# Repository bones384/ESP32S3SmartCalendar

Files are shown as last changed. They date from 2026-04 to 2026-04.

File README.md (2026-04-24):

# E-Paper Smart Calendar
A low-power smart calendar device that displays upcoming events and weather information on an e-paper screen. Built around the ESP32-S3, the system is designed for long battery life, minimal power consumption, and reliable offline persistence.
Built around the ESP32-S3, the system is designed for long battery life, minimal power consumption, and reliable offline persistence.

## Features
- Google Calendar & weather integration: Fetches event data from the user's Google Calendar and weather forecast information from open-meteo.
  - Synced data is cached and saved to FRAM, avoiding the need to resync on every reboot, saving power.
- Ultra-low power system with aggressive power gating: The entire system is power gated using a P-MOSFET and a TPL5110, waking periodically to update the display.
  - Network sync is expensive in terms of power, and as such only happens every few automatic wakes.
  - WiFi remains disabled outside of sync cycles.
  - E-paper display retains the image without power
  - Powered by 4xAA batteries (designed for NiMH),
  - Will display warning and reduce power usage to minimum if voltage goes under a safe threshold.
> [!NOTE]
> These power saving techniques reduce the idle power usage to under a microampere, with short bursts of power consumption during a wake cycle.
> This increases battery life significantly.
- Interactive mode: The user can wake the device and browse events/forecasts for upcoming days.
- ESP SoftAP WiFi Provisioning: Network credentials can be configured from a mobile device using Espressif’s provisioning tools.
- Google API tokens are provisioned via serial connection and automatically refreshed when expired.
- Displays indoor temperature and humidity using onboard sensors.

## Key Components

* ESP32-S3 DevkitC-1
* Adafruit SHT40 breakout board (ADAFRUIT4885)
* 4MBit FRAM IC: MB85RS4MTPF-G-BCERE1, with a matching DIP adapter
* Pololu 3.3V step-down voltage regulator module DT24V10F3
* Waveshare 13353 4.2 inch E-Paper module
* TPL5110 Low Power Timer (with matching DIP adapter)
  
A full BOM can be found in the project report in the docs directory.

## Media

High-level system diagram:
system-diagram
Software flow diagram:
flowidag

## Notes
Includes full schematic (.sch) and PCB layout (.brd) files.
Designed as a custom PCB and manufactured via JLCPCB.
All components were hand-soldered and the device was fully assembled and tested.
The /docs directory contains a detailed report with the BOM, assembly guide, and operating instructions.

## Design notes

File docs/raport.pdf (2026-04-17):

| Katedra Grafiki Wizji Komputerowej i Systemów Cyfrowych Raport z projektu SMiW

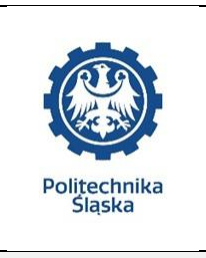
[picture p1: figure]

Rok akademicki | Rodzaj studiów*: SSI Glw/SSI Ktw/NSI Glw | Dizeń tygodnia i godzina zajęć: | Numer sekcji:
2025/2026 | SSI Glw | Środa 11:30 | 7
Imię: Nazwisko: | Mateusz | Prowadzący (inicjały): OA/JP/GB/KP | JP

## Kowalec

## Temat projektu

# Smart Calendar

Opis głównych założeń projektu:

- Wyświetlacz e-papier
- Pobiera dane o prognozie pogody oraz wydarzenia z kalendarza użytkownika z Internetu
- Wyświetla aktualną godzinę oraz zmierzoną temperaturę i wilgotność otoczenia
- Konfiguracja ustawień sieci przez BT

Rodzaj zasilania:

- Zasilanie bateryjne (AA NiMH)

Mateusz Kowalec INF-4 | Raport projektu SMIW | Bytom, 12 Luty 2026

## Szczegółowy opis funkcjonalności projektu:

Celem projektu jest stworzenie „mądrego” kalendarza. Podobnie do wersji papierowej, będzie można zaobserwować na nim aktualną datę, dowiedzieć się, czy danego dnia nie wypada święto, czyje są imieniny itd. Jedną z przewag takiego urządzenia nad tradycyjnym jest to, że po zamontowaniu w miejscu docelowym wymaga jedynie okazjonalnej wymiany baterii, a nie corocznej zmiany.

Jako urządzenie „mądre” będzie pokazywać prognozę pogody na najbliższe parę tygodni, pobraną z ogólnodostępnego API, Open-Meteo, oraz wydarzeń z kalendarza użytkownika w Google Calendar. Możliwe jest „przybliżenie” konkretnego dnia, co pozwoli wyświetlić dokładniejszą prognozę pogody (godzinową) oraz wydarzenia występujące w danym dniu. Dla dodatkowej wygody kalendarz będzie również wyświetlać aktualną godzinę, temperaturę, oraz wilgotność – jednocześnie zastępuje więc kalendarz, planer, zegar, pogodynkę, termometr oraz higrometr.

By zwiększyć komfort użycia (i zmniejszyć zużycie baterii) wykorzystany został wyświetlacz epapier. Celem wydłużenia żywotności baterii, urządzenie będzie spędzać większość czasu w stanie spoczynku, wybudzając się jedynie co minutę w celu aktualizacji czasu na wyświetlaczu. Natomiast raz na konfigurowalny okres czasu urządzenie będzie wybudzać się celem połączenia z internetem, pobraniem nowych danych pogodowych oraz kalendarzowych, zsynchronizowanie czasu, wyłączenia radia, zaktualizowania wyświetlacza oraz jak najszybszego odcięcia sobie zasilania.

Interakcja użytkownika, rozpoczynana przyciskiem włączenia na płytce, wykonywana przełącznikiem nawigacyjnym podobnym w obsłudze do selektora na pilocie do telewizora, wybudza urządzenie z uśpienia, do którego powróci po dłuższym czasie bezczynności.

By nie musieć przeprogramowywać urządzenia w przypadku zmian ustawień sieciowych lub zmiany lokalizacji, dane o WiFi będą aktualizowane za pomocą aplikacji na telefonie (ESP WiFi provisioning, oryginalnie miało być to BLE, ostatecznie jest SoftAP, więcej we wnioskach).

Udzielanie dostępu do usług Google użytkownika jest wykonywane za pomocą przesłania kodu dostepu Google API przy pierwszym uruchomieniu urządzenia przez kabel USB podpięty do komputera. Urządzenie będzie zasilane bateriami AA NiMH. Bateriami, bo domyślnie ma zostać zamontowane na ścianie lub przypięte do tablicy korkowej, gdzie będzie wisieć nieściągane przez cały swój okres używania, a akumulatorki NiMH – bo takie wraz z ładowarką mam pod ręką.

## Wybory najważniejszych części:

Czujnik wilgoci/temperatury:
| HDC3020 | HDC1000YPAR | Sensirion SHTC3 | Sensiron SHT40
Dokładność pomiarów | +/- 0,1C, +-0,5% | +/- 0,2C, +-3% | +-0,2C, +-2% | +-0,1C +-1.0%
Zakres temperatur | -40 do 125C | -40C do 125C | -40C do 125C | -40 do 125C
Interfejs | I2C | I2C | I2C | I2C
Napięcie zasilania | 1.6V-5.5V | 3V - 5V | 1,62V-3,6V | 1,08V-3,6V
Czas reakcji pomiaru RH | 4s | 15s | 8s | 6s
Sprawiłby się tu dowolny czujnik o dokładności temperatury ok. +/- 0.1C i wilgotności +/- 1%. Oryginalnie planowałem zamówić sam czujnik HDC3020, natomiast okazał się on zbyt mały by ręcznie go lutować (szczególnie, że nie mam płyty grzewczej). Zamówiłem więc breakout board SHT40 Adafruita, bo również spełnia moje wymagania, był w momencie zamawiania części dostępny w polskich magazynach i jest w akceptowalnej dla mnie cenie.

Przełącznik 5-kierunkowy:
Oryginalnie planowałem wybrać Adafruit SKQUCAA010, natomiast w celu zmniejszenia kosztów dostawy zamówiłem od innego dostawcy prawie identyczny przełącznik E-Switch JS5208. Projekt działałby praktycznie identycznie gdyby zamiast tego przełącznika dać np. 5 tact switchy, natomiast pojedyńczy przełącznik wygodniej się obsługuje.

Przetwornica:
| Pololu D24V10F3 | TI TPS62840 | Analog Devices ADP2370
Maks. prąd wyj. | 1A | 750mA | 3A
Min. napięcie wej. | 3,5V | 1,8V | 3,2V
IQ | 1-4mA | 60nA | 34uA
Sprawdziłby się tu dowolny moduł przetwornicy Buck 3.3V, umożliwiający pobór przynajmniej 1A przy VIn=4V (Dropout voltage @1A = 0.7V lub mniej).
Wybrałem Pololu D24V10F3, bo to gotowy i prosty w zastosowaniu moduł z induktorem na płytce, który na pewno przyda mi się do przyszłych projektów. Prąd spoczynkowy okazał się nie mieć tutaj znaczenia - w stanie czuwania układu wejście zasilania przetwornicy jest kompletnie odcięte.

Mikrokontroler:
| ESP32-S3-DEVKIT-C1 | ESP32-C6-DevkitM-1 | ESP32-C3-DevKitM-1
Procesor | ESP32-S3-WROOM-1 | ESP32-C3-MINI-1 | ESP32-C6-MINI-1
Rdzenie | 2 | 1 | 1
Pobór prądu w stanie uśpienia | Kilka uA
GPIO | 45 | 22 | 13
WiFi, BT | Tak | Tak | Tak
Wybrana została płytka rozwojowa ESP32-S3-DevKitC-1. Dużymi atutami tych mikrokontrolerów jest własna aplikacja do WiFi provisioning Espressif’a (ESP BLE/SoftAP Provisioning) + odpowiednia biblioteka, wbudowane wsparcie BT/WiFi + antena, niski pobór prądu (szczególnie w stanach uśpienia, choć końcowo nie miało to znaczenia), pełna kompatybilność z bibliotekami Arduino (pod warunkiem odpowiedniego skonfigurowania środowiska esp-idf) oraz niska cena. W ramach projektu z semestru letniego miałem już okazję zaznajomić się z procesorami z tej rodziny, a ten konkretny devkit już posiadam (nawet w dwóch egzemplarzach).

Projekt został zrealizowany w Autodesk EAGLE / ESP-IDF(Wersja linuksowa) + CLion + Arduino (IDF Component) .

## Schemat blokowy urządzenia:

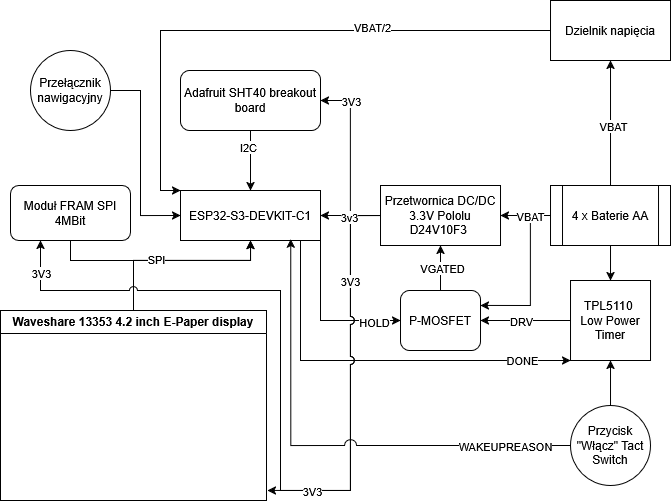
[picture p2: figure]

## Schemat ideowy:

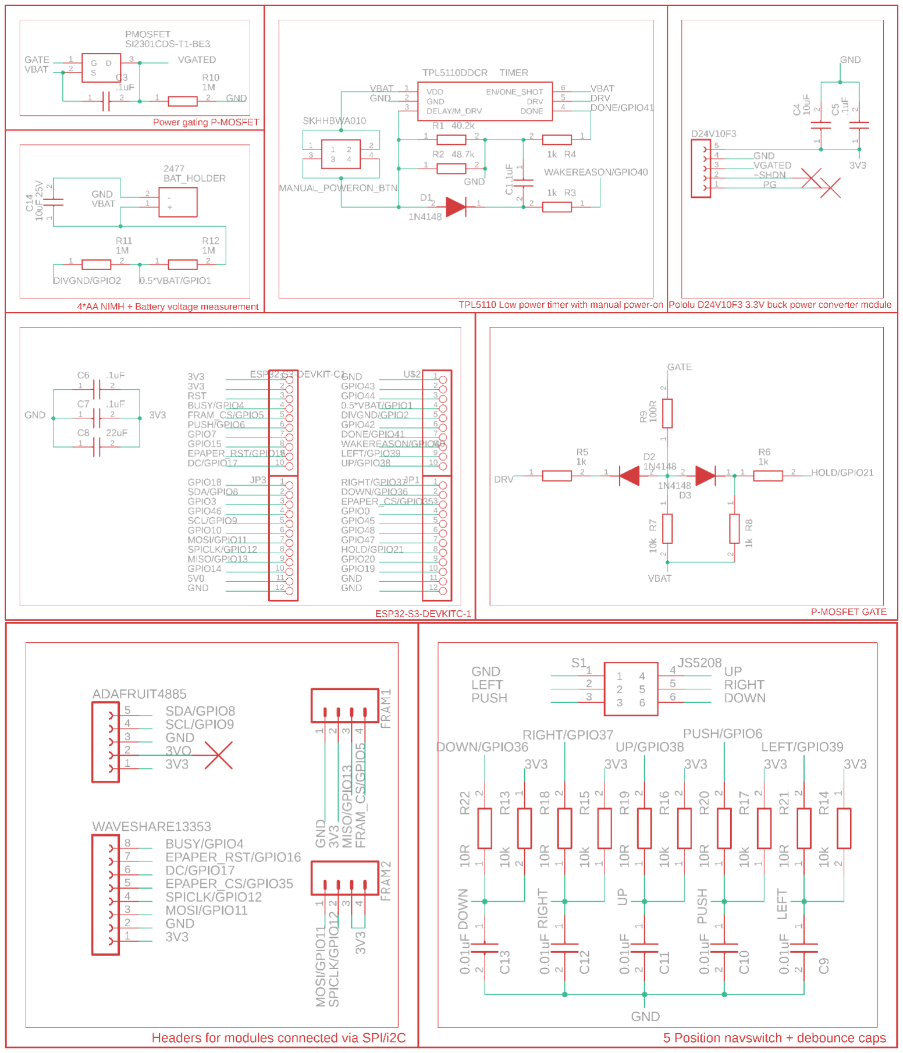
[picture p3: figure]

## Opis funkcji bloków/elementów

Blok przetwornica – mikrokontroler – wyświetlacz + czujniki + przełącznik nawigacyjny raczej nie potrzebuje wytłumaczenia. O wiele ciekawszy natomiast jest blok bramkowania zasilania, składający się z TPL5110 Low Power Timer, tranzystora MOSFET z kanałem typu P oraz tact switcha.

Potrzebujemy wybudzać mikrokontroler tylko raz na minutę (celem aktualizacji informacji na wyświetlaczu: zegara oraz informacji z czujników – taki układ pozwala uzyskać prawie zerowy prąd spoczynkowy, wtedy kiedy tylko TPL5110 pobiera prąd max 50nA. Same działanie bloku jest proste: Tranzystor kontroluje przepływ prądu pomiędzy VBAT a VIN przetwornicy, odcinając przetwornice oraz całą resztę układu do niej podłączonego od zasilania.

TPL5110 co konfigurowalną (poprzez opór na wejściu DELAY/M_DRV) długość czasu, nazwijmy ją t, generuje stan niski na wyjściu DRV, podłączonym do bramki tranzystora. Bez żadnej interakcji ze strony mikrokontrolera układ utrzymywałby stan niski na DRV przez t − 50ms, po czym na ostatnie 50ms cyklu ustawiłby tam stan wysoki, odcinając na chwilę zasilanie i restartując układ. Mikrokontroler może przekazać timerowi informację o zakończeniu pracy, wysyłając odpowiedni impuls na wejście DONE, co skutkuje natychmiastowym odcięciem zasilania. Co ważne, timer generuje impulsy na DRV dokładnie co t, niezależnie od wysłania sygnału DONE.

Timer ma również funkcję ręcznego włączenia, realizowaną poprzez osobny tact switch przy układzie zasilającym, podpięty do jego wejścia DELAY/M_DRV. Naciśnięcie przycisku skutkuje nadaniem napięcia VDD na to wejście, co powoduje ustawienie linii DRV na stan niski (nie wpływając na odliczanie czasu przez timer!). Przycisk jest również podłączony do procesora, wraz z
kondensatorem "przetrzymującym" informację o naciśnięciu przycisku (timer reaguje na ręczne włączenie z lekkim opóźnieniem), co pozwala po włączeniu mikrokontrolera sprawdzić czy wybudzenie było automatyczne, czy ręczne, i odpowiednio dopasować tok programu. Oprócz timera, do bramki tranzystora podłączone jest również wyjście procesora, nazwane przeze mnie "HOLD", które procesor zaraz po wybudzeniu zwiera do masy. Dopuki HOLD = GND, procesor nie utraci zasilania, nawet jeśli timer odliczy minutę od ostatniego autmatycznego impulsu (DRV i HOLD przechodzą przez diody sygnałowe, mogą więc jedynie wpłynąć na bramkę ustawiając stan niski lub GND, co skutkuje włączeniem zasilania, natomiast żadne ze źródeł nie może wywołać tam stanu wysokiego, który jest domyślnie osiągany poprzez rezystor podciągający.

Cykl działania bloku wygląda więc następująco:
1. TPL5110 albo w skutek upłynięcia czasu t lub naciśnięcia przycisku ustawia DRV na stan niski
2. Mosfet przewodzi: Przetwornica zasila procesor
3. Procesor po włączeniu podtrzymuje zasilanie ustawiając hold na gnd
4. Procesor odczytuje informację o powodzie wybudzenia z linii WAKEREASON
5. Procesor wykonuje swoje zadania
6. Po zakończeniu działania, procesor najpierw wysyła impuls na linię DONE, by zasygnalizować TPL5110 by tamten przestał podtrzymywać zasilanie jeśli aktualnie to robi. Teraz DRV jest w stanie wysokim, i nie wpływa na bramkę tranzystora. Tylko HOLD utrzymuje teraz zasilanie.
7. Procesor ustawia HOLD na stan wysokiej impedancji, odcinając zasilanie do przetwornicy i co za tym idzie do reszty układu. Układ zużywa teraz znikomy prąd w oczekiwaniu na kolejne wydarzenie, które skutkowałoby wybudzeniem.

By jeszcze bardziej skapitalizować na bramkowaniu zasilania, do układu dodano moduł F-RAM 4Mbit RAMXEED (MB85RS4MTPF-G-BCERE1), co umożliwia cachowanie danych pobranych z internetu pomiędzy uruchomieniami. Pozwala to przez większość tych uruchomień nie włączać radia, a jedynie pobierać zcachowane dane z modułu. W NVS procesora przechowywany jest ostatni zsynchronizowany timestamp, oraz liczba wybudzeń do pełnej synchronizacji. Aktualny czas jest wyliczany ufając częstotliwości automatycznych wybudzeń jako czas ostatniej syncℎronizacji +
liczba wybudzeń od ostatniej syncℎronizacji ∗ 60s. Procesor tylko co parę automatycznych uruchomień / przy ręcznym pobiera świeże dane z internetu.

## Projekt płytki/schemat montażowy

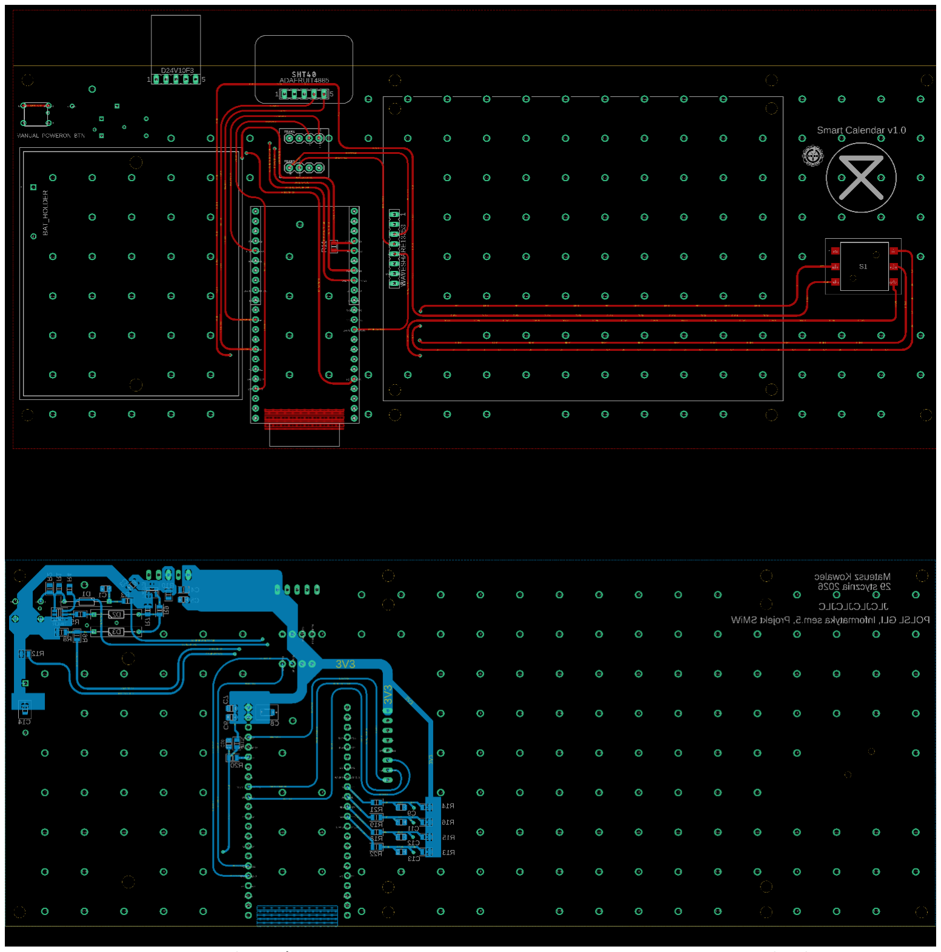
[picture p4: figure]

Zdjęcia warstwy górnej/dolnej płytki pcb. Pola masy, dla lepszej widoczności ścieżek i komponentów, zostały ukryte – w rzeczywistości wypełniają całe pozostałe wolne miejsce na płytce.

## Lista elementów (BoM, export z EAGLE):

Part | Value | Device | Package | Description
Adafruit SHT40 | | ADAFRUIT4885 | | Temperature & Humidity Sensor
BAT_HOLDER | 2477 | 2477 | 2477 | Cylindrical Battery Contacts, Clips, Holders & Springs 4AA PLASTIC HOLDER
C1 | .1uF | 0805ZC104JAZ2A | CAPC2012X94N | Multilayer Ceramic Capacitors MLCC -SMD/SMT 10V .1uF X7R 0805 5% Tol FLEX
C3 | .1uF | 0805ZC104JAZ2A | CAPC2012X94N | Multilayer Ceramic Capacitors MLCC -SMD/SMT 10V .1uF X7R 0805 5% Tol FLEX
C4 | 10uF | GCM21BR71A106K E22L | CAPC2012X140N | Murata GCM21BR71A106KE2 2L 10uF Multilayer Ceramic Capacitor MLCC 10V dc +/-10% Tolerance SMD
C5 | .1uF | 0805ZC104JAZ2A | CAPC2012X94N | Multilayer Ceramic Capacitors MLCC -SMD/SMT 10V .1uF X7R 0805 5% Tol FLEX
C6 | .1uF | 0805ZC104JAZ2A | CAPC2012X94N | Multilayer Ceramic Capacitors MLCC -SMD/SMT 10V .1uF X7R 0805 5% Tol FLEX
C7 | .1uF | 0805ZC104JAZ2A | CAPC2012X94N | Multilayer Ceramic Capacitors MLCC -SMD/SMT 10V .1uF X7R 0805 5% Tol FLEX
C8 | 22uF | GRM31CR71A226K E15L | GRM31X | MLCC, 1206
C9 | 0.01u F | 0805ZC103KAT2A | CAPC2012X94N | Capacitor 0805 10000PF +/-10% 10V
C10 | 0.01u F | 0805ZC103KAT2A | CAPC2012X94N | Capacitor 0805 10000PF +/-10% 10V
C11 | 0.01u F | 0805ZC103KAT2A | CAPC2012X94N | Capacitor 0805 10000PF +/-10% 10V
C12 | 0.01u F | 0805ZC103KAT2A | CAPC2012X94N | Capacitor 0805 10000PF +/-10% 10V
C13 | 0.01u F | 0805ZC103KAT2A | CAPC2012X94N | Capacitor 0805 10000PF +/-10% 10V
C14 | 10uF 25V | GCM21BC71E106K E36K | GCM21 | Chip Multilayer Ceramic Capacitors for Automotive

| | | | (Powertrain/Safety), 1.6 x 0.8 (0603)
D1 | 1N41 48 | 1N4148 | DIOAD1150W50L390 D190 | Diodes - General Purpose, Power, Switching Small Signal Diode, DO-35, 100V, 0.2A, 175C
D2 | 1N41 48 | 1N4148 | DIOAD1150W50L390 D190 | Diodes - General Purpose, Power, Switching Small Signal Diode, DO-35, 100V, 0.2A, 175C
D3 | 1N41 48 | 1N4148 | DIOAD1150W50L390 D190 | Diodes - General Purpose, Power, Switching Small Signal Diode, DO-35, 100V, 0.2A, 175C
D24V10F3 | | Pololu D24V10F3 | | Pololu 3.3V, 1A Step-Down Voltage Regulator D24V10F3
ESP32-S3-DEVKIT-C1 | | | ESP32-S3-DEVKIT-C1 | WiFi Development Tools - 802.11 WiFi Development Tools -802.11 ESP32-S3 general-purpose development board, embeds ESP32-S3-WROOM-1, 8 MB Quad flash and 8MB Octal PSRAM, with pin header
FRAM1 | | CONN_04PTH | 1X04 | Multi connection point. Often used as Generic Header-pin footprint for 0.1 inch spaced/style header connections
FRAM2 | | CONN_04PTH | 1X04 | Multi connection point. Often used as Generic Header-pin footprint for 0.1 inch spaced/style header connections
FRAM | | MB85RS4MTPF-G-BCERE1 | | F-RAM F-RAM 4Mbit FeRAM with SPI interface - SOP8 (208mil) T&R
JP1 | | PINHD-1X12-CB | 1X12-CB | PIN HEADER
JP3 | | PINHD-1X12-CB | 1X12-CB | PIN HEADER
MANUAL_POWERON _BTN | | SKHHBWA010 | SKHHALA010 | Tact switch,PCB,SPST,grey, 1.57N op/force Grey Stem Tactile Switch, SPST-NO 50 mA 7mm
PMOSFET | | SI2301CDS-T1-BE3 | SOT95P237X112-3N | MOSFET P-CHANNEL 20-V (D-S)
R1 | 40.2k | CR0805-FX-4022ELF | RESC2012X60N | Thick Film Resistors -SMD 40.2K 1%
R2 | 48.7k | CR0805-FX-4872ELF | RESC2012X60N | Thick Film Resistors -SMD 48.7K 1%
R3 | 1k | CRCW08051K00FK TC | RESC2012X50N | VISHAY -CRCW08051K00FKTC

| | | | - RES, THICK FILM, 1K, 1%, 0.125W, 0805
R4 | 1k | CRCW08051K00FK TC | RESC2012X50N | VISHAY -CRCW08051K00FKTC - RES, THICK FILM, 1K, 1%, 0.125W, 0805
R5 | 1k | CRCW08051K00FK TC | RESC2012X50N | VISHAY -CRCW08051K00FKTC - RES, THICK FILM, 1K, 1%, 0.125W, 0805
R6 | 1k | CRCW08051K00FK TC | RESC2012X50N | VISHAY -CRCW08051K00FKTC - RES, THICK FILM, 1K, 1%, 0.125W, 0805
R7 | 10k | RK73H2ATTE1002F | RESC2012X60N | Thick Film Resistors SMD1/4watts10Kohms 1%
R8 | 1k | CRCW08051K00FK TC | RESC2012X50N | VISHAY -CRCW08051K00FKTC - RES, THICK FILM, 1K, 1%, 0.125W, 0805
R9 | 100R | CRCW0805100RFK EA | RESC2012X50N | Vishay CRCW Series Thick Film Surface Mount Resistor 0805 Case 100?? ??1% 0.125W ??100ppm/??C
R10 | 1M | MCU08050C1004FP 500 | RESC2012X62N | 1 MOhms +/-1% 0.2W, 1/5W Chip Resistor 0805 (2012 Metric) Anti-Sulfur Thin Film
R11 | 1M | MCU08050C1004FP 500 | RESC2012X62N | 1 MOhms +/-1% 0.2W, 1/5W Chip Resistor 0805 (2012 Metric) Anti-Sulfur Thin Film
R12 | 1M | MCU08050C1004FP 500 | RESC2012X62N | 1 MOhms +/-1% 0.2W, 1/5W Chip Resistor 0805 (2012 Metric) Anti-Sulfur Thin Film
R13 | 10k | RK73H2ATTE1002F | RESC2012X60N | Thick Film Resistors SMD1/4watts10Kohms 1%
R14 | 10k | RK73H2ATTE1002F | RESC2012X60N | Thick Film Resistors SMD1/4watts10Kohms 1%
R15 | 10k | RK73H2ATTE1002F | RESC2012X60N | Thick Film Resistors SMD1/4watts10Kohms 1%
R16 | 10k | RK73H2ATTE1002F | RESC2012X60N | Thick Film Resistors SMD1/4watts10Kohms 1%
R17 | 10k | RK73H2ATTE1002F | RESC2012X60N | Thick Film Resistors SMD1/4watts10Kohms 1%
R18 | 10R | CRCW0805100RFK EA | RESC2012X50N | Vishay CRCW Series Thick Film Surface Mount Resistor 0805 Case 100?? ??1% 0.125W ??100ppm/??C
R19 | 10R | CRCW0805100RFK EA | RESC2012X50N | Vishay CRCW Series Thick Film Surface

| | | | Mount Resistor 0805 Case 100?? ??1% 0.125W ??100ppm/??C
R20 | 10R | CRCW0805100RFK EA | RESC2012X50N | Vishay CRCW Series Thick Film Surface Mount Resistor 0805 Case 100?? ??1% 0.125W ??100ppm/??C
R21 | 10R | CRCW0805100RFK EA | RESC2012X50N | Vishay CRCW Series Thick Film Surface Mount Resistor 0805 Case 100?? ??1% 0.125W ??100ppm/??C
R22 | 10R | CRCW0805100RFK EA | RESC2012X50N | Vishay CRCW Series Thick Film Surface Mount Resistor 0805 Case 100?? ??1% 0.125W ??100ppm/??C
S1 | | JS5208 | | JS5208 NAVIGATION, Surface Mount
TIMER | | TPL5110DDCR | SOT95P280X110-6N | Timers & Support Products Ultr LowPowrTimerMOS drivr MOSFET Powr
U$2 | | PINHD-1X10 | 1X10-BIG | Pin header 1x10 0.1" spacing
WAVESHARE13353 | | WAVESHARE13353 | | 4.2inch e-Paper Module

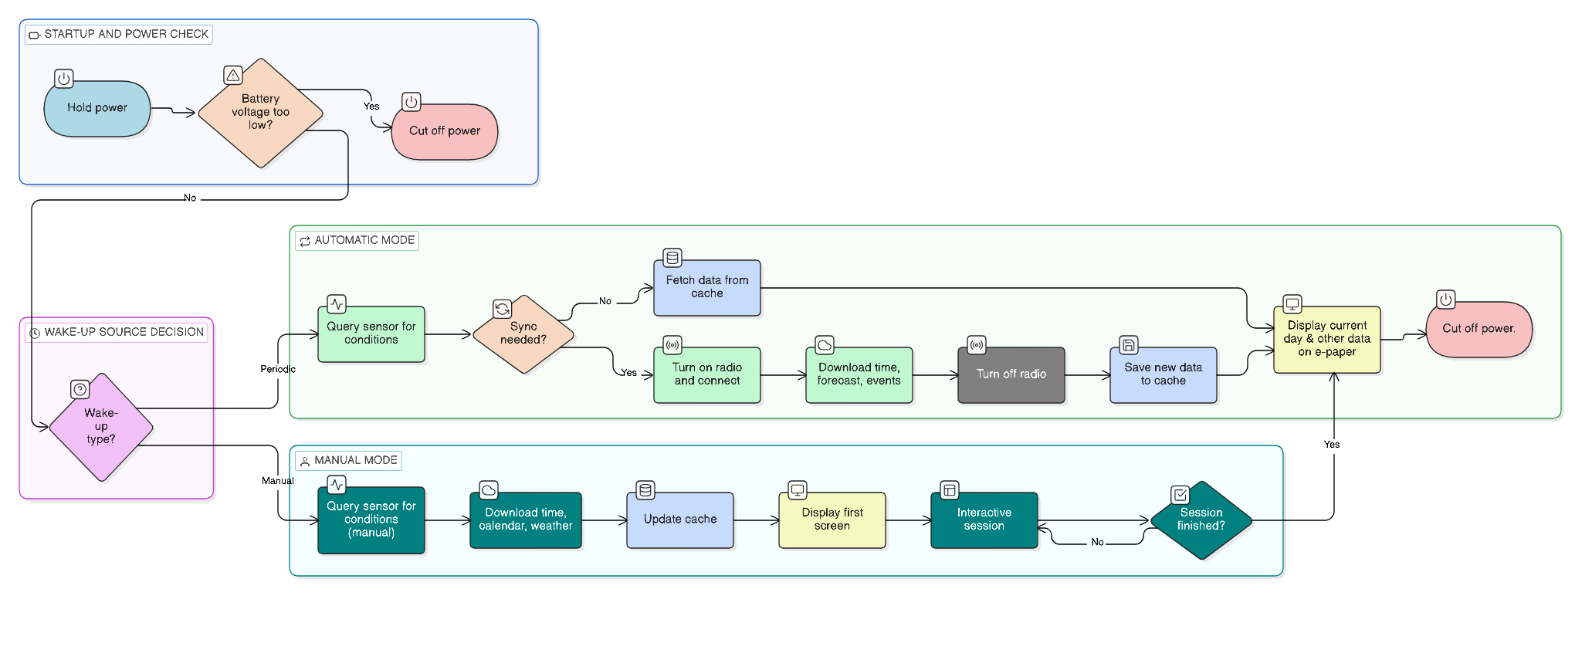
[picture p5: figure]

## Algorytm oprogramowania

- Tok programu:
- Podtrzymanie zasilania (HOLD = GND)
- Sprawdzenie czy napięcie na baterii nie jest zbyt niskie (jeśli tak – od razu odcinamy zasilanie DONE = 1)
- Sprawdzenie czy wybudzenie jest ręczne, czy okresowe
- Jeśli okresowe:
- Odpytać sensor o aktualne warunki.
- Sprawdzić, czy od ostatniej synchronizacji nie minęło zbyt wiele uruchomień (licznik w nvs)
- Jeśli jeszcze nie potrzebujemy synchronizacji:
- Pobrać z fram-u ostatnio scachowane dane, z nvs pobrać poprzednio zapisany czas, zinkrementować go o jedną minutę, zapisać.
- Jeśli jej potrzebujemy:
- Włączyć radio, połączyć się z internetem.
- Pobrać z internetu aktualny czas, prognozę, wydarzenia.
- Wyłączyć radio.
- Zapisać nowe dane w framie.
- Wyświetlić zebrane dane na wyświetlaczu e-papier.
- Odciąć zasilanie (HOLD = High-Z, DONE = 1).
- Jeśli ręczne:
- Odpytać sensor o aktualne warunki.
- Pobrać z Internetu aktualny czas, dane z kalendarza i o prognozie pogody.
- Zaktualizować cache w framie i dane w nvs.
- Wyświetlić pierwszy ekran na wyświetlaczu.
- Od tej pory zaczyna się sesja interaktywna – użytkownik porusza się po GUI, przeglądając daty lub zmieniając ustawienia.
- Na życzenie użytkownika lub po minięciu jakiegoś czasu bez interakcji przechodzimy do obsługi jak w okresowym wybudzeniu.

## Zmienne i procedury

Podczas pisania programu korzystałem ze strategii „dziel i zwyciężaj”, rozkładając wszystkie pożądane funkcjonalności na elementarne funkcje, o coraz bardziej specyficznym działaniu, odpowiednio sklejane by uzyskać pożądany efekt. Skutkuje to zbyt dużą liczbą małych funkcji, by opisać wszystkie. Opiszę więc tylko te najważniejsze:
- void staticDraw(const Date &d, tm now)
- Wyświetla na wyświetlaczu epapier informacje pobrane wcześniej z sensorów oraz dane z cache’a na temat konkretnej daty. Wykorzystywany przy automatycznym wybudzeniu lub przy wyjściu z ręcznego by pokazać podgląd aktualnego dnia.
- void loopUI(Date currentDate)
- Inicjalizuje pętle trybu interaktywnego, zaczynając od podanej daty.
- void manual() i void automatic()
- Główne funkcje rozdzielające tok program dla konkretnego sposobu wybudzenia.
- void end()
- Odcięcie zasilania (DONE = 1, HOLD = HIGH-Z)
- std::multimap<Date, Event> event_map;
- Po pobraniu danych (z internetu lub cache) grupuje wydarzenia oraz dzień w którym się odbywają.
- Zmienna globalna, inicjalizowana tylko raz.
- std::map<Date, Forecast> forecast_map;
- Po pobraniu danych (z internetu lub cache) przechowuje prognozę pogody dla dni dla których ją mamy.
- Zmienna globalna, inicjalizowana tylko raz.
- void networkSync()
- Wewnętrznie składa się z wielu funkcji, np. connect(), getEvents(), loadEvents() itp.
- Synchronizuje czas, wydarzenia oraz prognozę pogody z internetu, wypełniając wymienione wyżej zmienne oraz zapisując efekt do cache.
- void loadFromCache() i void saveToCache()
- Zapisują lub pobierają dane z/do framu.
- String getAccessToken()
- Zwraca access token jeśli mamy takowy w NVS, jeśli nie – generuje nowy za pomocą refresh tokena, jeśli go mamy. Jeśli nie mamy refresh tokena – zwraca pusty String.
- tm getTime()
- Sprawdza czy zsynchronizowana już czas. Jeśli tak – zwraca go. Jeśli nie – synchronizuje go z internetem i zwraca uzyskany czas.
- float battery_voltage()
- Mierzy i zwraca napięcie baterii w woltach.

Ze względu na liczbę funkcji zostały one w większości pogrupowane do wielu plików nagłówkowych, o nazwie takiej, jak ich zastosowanie.

## Specyfikacja zewnętrzna

Sterowanie urządzeniem odbywa się za pomocą jedynie dwóch elementów kontrolnych: przycisku włączenia, w lewym górnym rogu urządzenia, oraz przełącznika nawigacyjnego, po prawej stronie wyświetlacza. W stanie domyślnym wyświetlacz wyświetla dane z poprzedniego uruchomienia, które miało miejsce nie więcej niż minutę temu: czas, dane z sensorów, napięcie baterii oraz wydarzenia/prognoza na aktualną datę, jeśli takowe istnieją. Konkretniej: Na pasku górnym wyświetla się aktualny czas, temperatura, wilgotność, SSID stacji Wi-Fi oraz napięcie na baterii; W dolnej części zależnie od trybu albo pojawia się aktualna data wraz z ogólną prognozą + tabelą prognozy godzinowej i liczbą wydarzeń w danym dniu lub w trybie wyświetlania wydarzeń – konkretne wydarzenie (tytuł, opis, godzina początku/końca).

Przycisk włącz służy jedynie do wejścia w tryb interaktywny. W trybie tym przełącznik nawigacyjny pozwala, za pomocą ruchu lewo-prawo, zmieniać datę dla której wyświetlamy dane. Dla dat które mają wydarzenia, możemy nacisnąć przycisk (PUSH), by wejść w tryb przeglądania wydarzeń – wtedy ruch lewo/prawo zmienia wydarzenie, występujące tego dnia, które przeglądamy. Ponowne naciśnięcie przycisku (PUSH) wraca do przeglądania prognoz/dat. W dowolnym momencie ruch góra/dół zaznacza lub oznacza pasek górny. Kiedy ten jest zaznaczony, można lewo/prawo wybrać tryb Provisioning albo Token refresh. Potwierdamy wybór naciśnięciem przycisku lub wychodzimy z paska górnego ruszając w dół. W trybie Provisioning korzystamy z instrukcji w aplikacji ESP SoftAP Provisioning, i czekamy aż układ się zsynchronizuje. W trybie Token refresh podpinamy urządzenia do komputera, i za pomocą np. idf.py monitor przesyłamy (wklejamy) access code do API Google, z minimum uprawnieniem Calendar.ReadOnly.
Wyjście z trybu interaktywnego jest albo automatyczne po 30s nieaktywności użytkownika lub po przytrzymaniu „dół” przez 3s.

## Montaż, programowanie, uruchamianie

Montaż układu najlepiej zacząć od przylutowania komponentów SMD na dolnej stronie płytki, następnie na górnej. Szczególną uwagę należy zachować przy lutowaniu układu TPL5110, gdyż ma on bardzo mały odstęp pomiędzy pinami – trzeba dopilnować, by nie utworzyły się mostki. Następnie należy przylutować headery na wyświetlacz oraz mikrokontroler (najlepiej je wpiąć podczas lutowania by nie wyszło krzywo). Wyświetlacz wypada dodatkowo przykręcić – wszystkie otwory na płytce są dopasowane do śrubek M3, dobrze zaopatrzyć się również w odpowiednie dystanse oraz nakrętki, najlepiej wszystko plastikowe. Moduł FRAM jest zamontowany na przejściówce SOP-8 -> DIP 8-pin – został do niej przylutowany by móc testować go na płytce stykowej. Uznałem, że nie chcę ryzykować z wylutowywaniem go z tej przejściówki, gdyż mam tylko jeden, a moduły FRAM są dość drogie. Moduł fram, przetwornice oraz sensor sht40 polecam zamontować poprzez bezpośrednie przylutowanie męskich headerów do płytki, pomijając żeńskie, by obniżyć profil urządzenia. Koszyk na baterie, który okazał się większy o ok. 1cm od danych producenta, najlepiej zamontować na sam koniec – ostatecznie jest bardzo mało miejsca między jego krawędzią a krawędziami headerów płytki procesora.

Cały układ został polutowany oraz złożony za pomocą standardowej lutownicy oraz cyny z dodatkiem ołowiu, na płytce zamówionej na JLCPCB.

Dla celów testowych użyty przeze mnie devkit miał już wylutowany stabilizator napięciowy (by móc debugować go nie wpływając na jego zasilanie). Jeśli chce się użyć niezmodyfikowanej płytki, trzeba pamiętać by przy programowaniu/przesyłaniu klucza nie mieć włożonych baterii, by układ na pewno był zasilany tylko z USB, lub po prostu wyciągnąć procesor z płytki.

Układ podpinamy do komputera, kompilujemy kod (najlepiej z folderu projektu (po wykonaniu source export.sh w folderze esp-idf oraz idf.py set-target esp32s3 w folderze projektu): idf.py –ccache flash. Dla zmodyfikowanej płytki przy debugowaniu wykonywałem idf.py –ccache flash size monitor.

Po zaprogramowaniu układu należy w opisany wcześniej sposób przekazać mu dane o Wi-Fi oraz kod do API Google. Układ nie potrzebuje dalszej konfiguracji.

Oprócz ręcznego testowania każdej funkcji, układ został również przetestowany poprzez zwykłe go użytkowanie – dodawanie wydarzeń do kalendarza Google i sprawdzanie czy wyświetlają się na nim, sprawdzanie prognozy pogody, zostawianie go włączonego na długi okres czasu, zmiana paremetrów stacji Wi-Fi routera itd.

## Wnioski, uwagi, problemy

Przede wszystkim: cały tok pracy z ESP32S3 okazał się bardzo przyjemny. IDF (przynajmniej na linuksie) szybko buduje projekt, jest w pełni zintegrowany z CLionem (szczególnie debugger świetnie działa). Dodawanie bibliotek Arduino jest również proste i wymaga w najgorszym przypadku dodania tylko pliku CMakeLists.txt ze stałą zawartością do folderu biblioteki. Możliwość zmiany ustawień interaktywnie przez menuconfig znacznie bardziej przypadła mi do gustu niż wpisywanie ich ręcznie w np. PlatformIO. Sam procesor ma naprawdę dużo funkcji, szczególnie za swoją cenę – więcej GPIO niż mam pomysłów na co je użyć, BLE + WiFi, kalibrowane pomiary napięcia, debugger, nvs, 16MB RAMu, dwa rdzenie na których łatwo mogę rozkładać pracę Taskami FreeRTOSa, pełna kompatybilność z bibliotekami Arduino wraz z możliwością korzystania/mieszania z bibliotekami esp-idf… Jestem bardzo zadowolony z produktu i zdecydowanie przy przyszłych projektach będę sięgać po procesory Espressifa.

Jeśli chodzi o problemy, wystąpiły zasadniczo dwa:

BLE Provisioning – oryginalnie, zgodnie z założeniami projektu, chciałem udostępniąć dane o Wi-Fi przez Bluetootha. Niestety, coś w aktualnej wersji arduino-esp32 uniemożliwiało mi skompilowanie scheme_ble.c, niezależnie od opcji w ustawieniach projektu CMake lub menuconfig. Po paru godzinach zabawy uznałem, że skoro pliki SoftAP kompilują się prawidłowo, a nie ma zbyt dużej różnicy pomiędzy ich używaniem (jeden parametr w funkcji provisioning ulega zmianie a użytkownik musi po prostu zainstalować inną aplikację), to po prostu zamienię sposób udostępniania połączenia.

Układ procesora w EAGLE – by uniknąć problemów z layoutem, procesor wraz z narysowanym przeze mnie silkscreenem oraz keepoutem pod anteną zostały przeze mnie pogrupowane do jednej grupy. W trakcie tworzenia projektu zachciało mi się obrócić procesor o 180 stopni, by antena wystawała poza płytkę, a wejścia do programowania dalej były łatwo dostępne (bo moduł FRAM jest niższy). Niestety, popełniłem na tym etapie jakiś błąd – którego nie zauważyłem przed potwierdzeniem produkcji płytki: Keepout wraz z rysunkiem modułu obróciłem, ale same headery pozostały w starej pozycji. Na szczęście, układ działa poprawnie, po prostu procesor jest „na odwrót” niż jak chciałem, a pod anteną na głównej płytce nie ma keepouta. Ze względu na podwyższenie procesora (jest w końcu wpięty headerheader) względem płytki, nie powinien to być zbyt duży problem.

Poza tym – wszystko poszło gładko i przyjemnie, a układ działa według oczekiwań.

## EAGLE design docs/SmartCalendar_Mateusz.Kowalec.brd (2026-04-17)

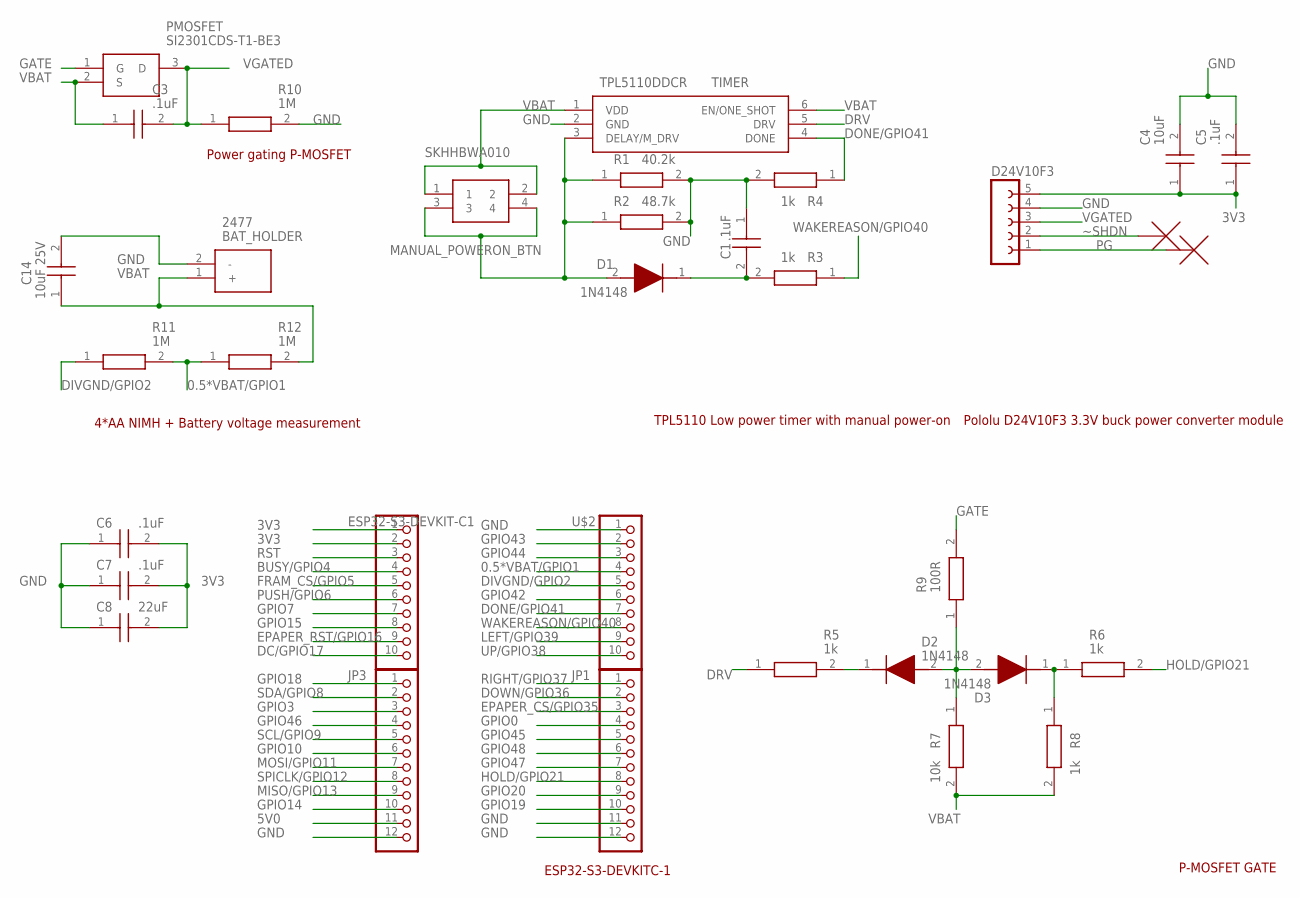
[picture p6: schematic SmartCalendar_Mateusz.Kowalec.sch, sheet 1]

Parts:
BAT_HOLDER: 2477
C1, C3, C5, C6, C7: .1uF; CAPC2012X94N
C4: 10uF; CAPC2012X140N
C8: 22uF; GRM31X
C14: 10uF 25V; GCM21
D1, D2, D3: 1N4148; DIOAD1150W50L390D190
D24V10F3: FE05-1
ESP32-S3-DEVKIT-C1: PINHD-1X10; 1X10-BIG
JP1, JP3: PINHD-1X12-CB; 1X12-CB
MANUAL_POWERON_BTN: SKHHBWA010; SKHHALA010
PMOSFET: SI2301CDS-T1-BE3; SOT95P237X112-3N
R1: 40.2k; RESC2012X60N
R2: 48.7k; RESC2012X60N
R3, R4, R5, R6, R8: 1k; RESC2012X50N
R7: 10k; RESC2012X60N
R9: 100R; RESC2012X50N
R10, R11, R12: 1M; RESC2012X62N
TIMER: TPL5110DDCR; SOT95P280X110-6N
U$2: PINHD-1X10; 1X10-BIG

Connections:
0.5*VBAT/GPIO1: R11.2, R12.1, U$2.4
3V3: C4.1, C5.1, C6.2, C7.2, C8.2, D24V10F3.5, ESP32-S3-DEVKIT-C1.1, ESP32-S3-DEVKIT-C1.2; also elsewhere on the board
5V0: JP3.11
BUSY/GPIO4: ESP32-S3-DEVKIT-C1.4; also elsewhere on the board
DC/GPIO17: ESP32-S3-DEVKIT-C1.10; also elsewhere on the board
DIVGND/GPIO2: R11.1, U$2.5
DONE/GPIO41: R4.1, TIMER.4 (DONE), U$2.7
DOWN/GPIO36: JP1.2; also elsewhere on the board
DRV: R5.1, TIMER.5 (DRV)
EPAPER_CS/GPIO35: JP1.3; also elsewhere on the board
EPAPER_RST/GPIO16: ESP32-S3-DEVKIT-C1.9; also elsewhere on the board
FRAM_CS/GPIO5: ESP32-S3-DEVKIT-C1.5; also elsewhere on the board
G: D2.2 (A), D3.2 (A), R7.1, R9.1
GATE: PMOSFET.1 (G), R9.2
GND: BAT_HOLDER.2 (-), C1.1, C4.2, C5.2, C6.1, C7.1, C8.1, C14.2, D24V10F3.4, JP1.11, JP1.12, JP3.12, R1.2, R2.2, R4.2, R10.2, TIMER.2 (GND), U$2.1; also elsewhere on the board
GPIO0: JP1.4
GPIO3: JP3.3
GPIO7: ESP32-S3-DEVKIT-C1.7
GPIO10: JP3.6
GPIO14: JP3.10
GPIO15: ESP32-S3-DEVKIT-C1.8
GPIO18: JP3.1
GPIO19: JP1.10
GPIO20: JP1.9
GPIO42: U$2.6
GPIO43: U$2.2
GPIO44: U$2.3
GPIO45: JP1.5
GPIO46: JP3.4
GPIO47: JP1.7
GPIO48: JP1.6
HOLD/GPIO21: JP1.8, R6.2
LEFT/GPIO39: U$2.9; also elsewhere on the board
MAN_REXT: D1.2 (A), MANUAL_POWERON_BTN.3, MANUAL_POWERON_BTN.4, R1.1, R2.1, TIMER.3 (DELAY/M_DRV)
MISO/GPIO13: JP3.9; also elsewhere on the board
MOSI/GPIO11: JP3.7; also elsewhere on the board
N: D2.1 (K), R5.2
unnamed: C1.2, D1.1 (K), R3.2
unnamed: D3.1 (K), R6.1, R8.1
PG: D24V10F3.1
PUSH/GPIO6: ESP32-S3-DEVKIT-C1.6; also elsewhere on the board
RIGHT/GPIO37: JP1.1; also elsewhere on the board
RST: ESP32-S3-DEVKIT-C1.3
SCL/GPIO9: JP3.5; also elsewhere on the board
SDA/GPIO8: JP3.2; also elsewhere on the board
SPICLK/GPIO12: JP3.8; also elsewhere on the board
UP/GPIO38: U$2.10; also elsewhere on the board
VBAT: BAT_HOLDER.1 (+), C3.1, C14.1, MANUAL_POWERON_BTN.1, MANUAL_POWERON_BTN.2, PMOSFET.2 (S), R7.2, R8.2, R12.2, TIMER.1 (VDD), TIMER.6 (EN/ONE_SHOT)
VGATED: C3.2, D24V10F3.3, PMOSFET.3 (D), R10.1
WAKEREASON/GPIO40: R3.1, U$2.8
~SHDN: D24V10F3.2

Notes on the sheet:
ESP32-S3-DEVKITC-1
4*AA NIMH + Battery voltage measurement
Power gating P-MOSFET
P-MOSFET GATE
TPL5110 Low power timer with manual power-on
Pololu D24V10F3 3.3V buck power converter module

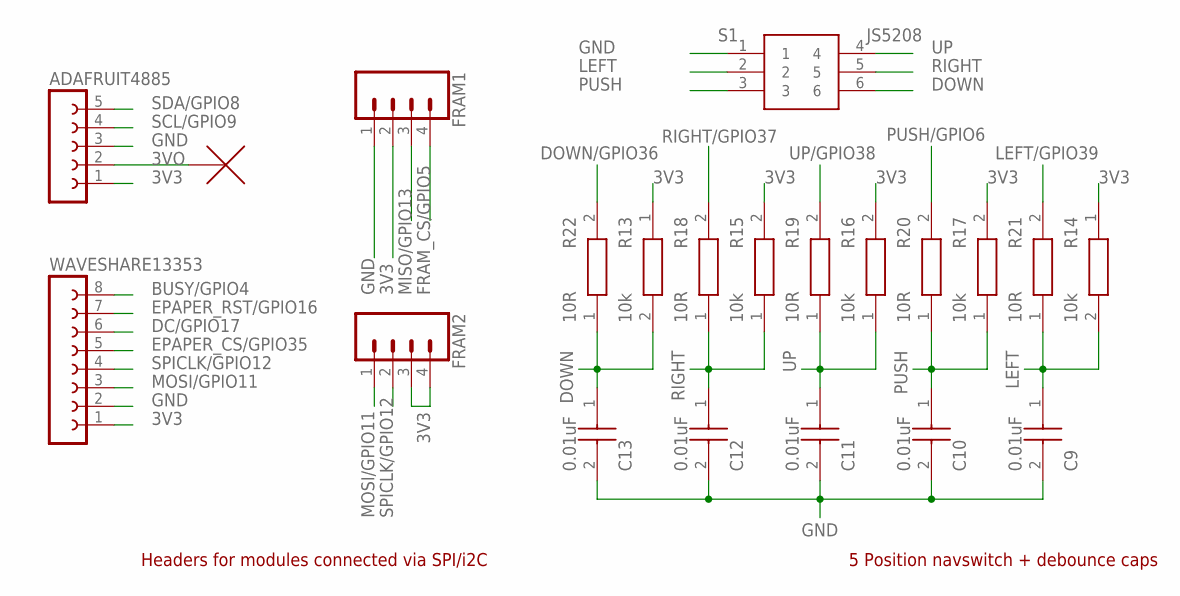
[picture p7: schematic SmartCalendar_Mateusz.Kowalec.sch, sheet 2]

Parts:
ADAFRUIT4885: FE05-1
C9, C10, C11, C12, C13: 0.01uF; CAPC2012X94N
FRAM1, FRAM2: CONN_04PTH; 1X04
R13, R14, R15, R16, R17: 10k; RESC2012X60N
R18, R19, R20, R21, R22: 10R; RESC2012X50N
S1: JS5208
WAVESHARE13353: FE08-1; FE08

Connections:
3V3: ADAFRUIT4885.1, FRAM1.2, FRAM2.3, FRAM2.4, R13.1, R14.1, R15.2, R16.2, R17.2, WAVESHARE13353.1; also elsewhere on the board
3VO: ADAFRUIT4885.2
BUSY/GPIO4: WAVESHARE13353.8; also elsewhere on the board
DC/GPIO17: WAVESHARE13353.6; also elsewhere on the board
DOWN: C13.1 (C1), R13.2, R22.1, S1.6
DOWN/GPIO36: R22.2; also elsewhere on the board
EPAPER_CS/GPIO35: WAVESHARE13353.5; also elsewhere on the board
EPAPER_RST/GPIO16: WAVESHARE13353.7; also elsewhere on the board
FRAM_CS/GPIO5: FRAM1.4; also elsewhere on the board
GND: ADAFRUIT4885.3, C9.2 (C2), C10.2 (C2), C11.2 (C2), C12.2 (C2), C13.2 (C2), FRAM1.1, S1.1, WAVESHARE13353.2; also elsewhere on the board
LEFT: C9.1 (C1), R14.2, R21.1, S1.2
LEFT/GPIO39: R21.2; also elsewhere on the board
MISO/GPIO13: FRAM1.3; also elsewhere on the board
MOSI/GPIO11: FRAM2.1, WAVESHARE13353.3; also elsewhere on the board
PUSH: C10.1 (C1), R17.1, R20.1, S1.3
PUSH/GPIO6: R20.2; also elsewhere on the board
RIGHT: C12.1 (C1), R15.1, R18.1, S1.5
RIGHT/GPIO37: R18.2; also elsewhere on the board
SCL/GPIO9: ADAFRUIT4885.4; also elsewhere on the board
SDA/GPIO8: ADAFRUIT4885.5; also elsewhere on the board
SPICLK/GPIO12: FRAM2.2, WAVESHARE13353.4; also elsewhere on the board
UP: C11.1 (C1), R16.1, R19.1, S1.4
UP/GPIO38: R19.2; also elsewhere on the board

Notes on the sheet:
5 Position navswitch + debounce caps
Headers for modules connected via SPI/i2C

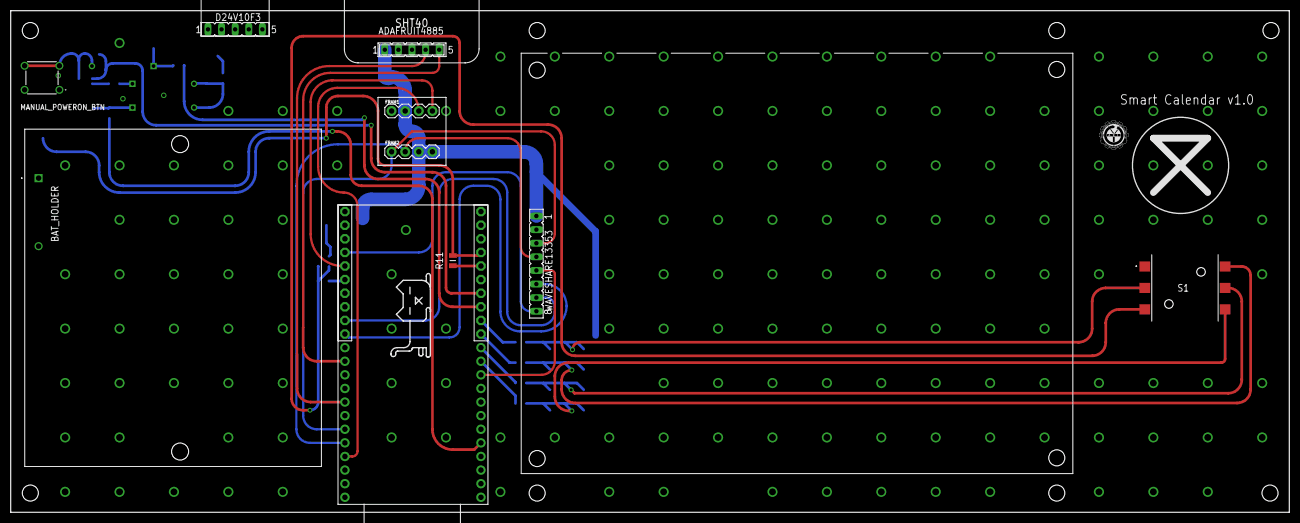
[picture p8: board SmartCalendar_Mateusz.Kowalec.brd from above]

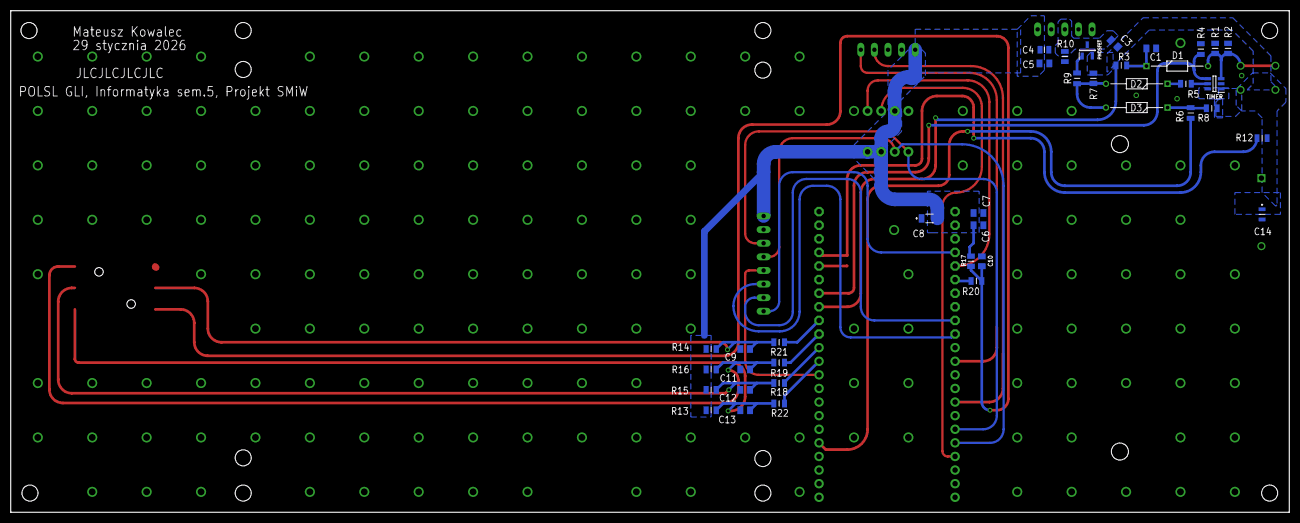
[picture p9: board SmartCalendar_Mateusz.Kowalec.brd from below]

Board: 2 copper layers, 238.7 x 93.7 mm, 52 parts (39 on the bottom side), 36 nets.

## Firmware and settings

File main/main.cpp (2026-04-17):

#include <Arduino.h>
#include <set>
#include <Adafruit_SHT4x.h>
#include <esp_phy_init.h>
#include <cstring>
#include <esp_wifi.h>
#include <WiFi.h>
#include <map>
#include <nvs.h>
#include <bitset>
#include "adc.hpp"
#include <WiFiProv.h>
#include "defines.h"
#include <cstdint>
#include <driver/rtc_io.h>
#include <misc/lv_color.h>
#include <HTTPClient.h>
#include <GxEPD2_3C.h>
#include <SPI.h>
#include <GxEPD2_BW.h>
#include <ArduinoJson.h>
#include <Preferences.h>
#include "adc.hpp"
#include "sync.hpp"
#include <ctime>

#include <lvgl.h>
#include "dbgprint.h"
#include <Adafruit_FRAM_SPI.h>
#include "time.hpp"
#include "fram.hpp"
#include "structs.hpp"
#include "tokens.hpp"
#include "connect.hpp"
GxEPD2_BW<GxEPD2_420_GDEY042T81, GxEPD2_420_GDEY042T81::HEIGHT> display(GxEPD2_420_GDEY042T81(CS_PIN, DC_PIN, RST_PIN, BUSY_PIN));

int is_manual;
void loop(void* arg);
void setup(void* arg);
extern "C" [[noreturn]] void app_main(void)
{
    initArduino();

    gpio_reset_pin(GPIO_NUM_40);
    gpio_reset_pin(GPIO_NUM_41);
    gpio_set_direction(GPIO_NUM_40,GPIO_MODE_INPUT);
    is_manual = gpio_get_level(GPIO_NUM_40);


    gpio_reset_pin(GPIO_NUM_41);
    gpio_set_direction(GPIO_NUM_41, GPIO_MODE_OUTPUT);
    gpio_set_direction(GPIO_NUM_21, GPIO_MODE_OUTPUT_OD);
    gpio_pullup_dis(GPIO_NUM_41);
    gpio_pullup_dis(GPIO_NUM_21);

    gpio_set_level(GPIO_NUM_21, 0); //HOLD
    gpio_set_level(GPIO_NUM_41, 0); //DONE



    TaskHandle_t setupHandle = nullptr;
    xTaskCreate(
            setup,
            "arduino_setup",
            20480, //8k might be enough?
            xTaskGetCurrentTaskHandle(),
            5,
            &setupHandle
    );
    ulTaskNotifyTake(pdTRUE, portMAX_DELAY);
    while (true) {
        xTaskCreate(
                loop,
                "arduino_loop",
                20480, //8k might be enough?
                xTaskGetCurrentTaskHandle(),
                5,
                &setupHandle
        );
        ulTaskNotifyTake(pdTRUE, portMAX_DELAY);
        vTaskDelay(1);
    }
}

auto sht4 = Adafruit_SHT4x();
void end();
Preferences prefs;

//Manual or first poweron of battery pack

void end()
{
    display.hibernate();
    prefs.end();
    DBG_PRINTLN("Buhbye!");
    gpio_set_level(GPIO_NUM_41,1); //DONE
    gpio_set_level(GPIO_NUM_21,1); //stop hold
    while(true) delay(500);
}

float vbat = 0.00f;
float humidity = 0.0f;
float temperature = 0.0f;
std::multimap<Date, Event> event_map;
std::map<Date, Forecast> forecast_map;

int selected = 1;           // 0 = header, 1 = body (body default now)
int header_section = 0;      // 0 = H2, 1 = H3
int partial_count = 0;
const int PARTIAL_LIMIT = 30;

bool btn_pressed(int gpio) {
    return digitalRead(gpio) == LOW;
}
tm dateToTm(const Date &d) {
    tm t = {};
    t.tm_year = d.year;
    t.tm_mon  = d.month;
    t.tm_mday = d.day;
    return t;
}
bool viewingEvents = false;
int eventIndex = 0;

void drawHeader(bool invert, int highlight_section = -1, tm now = getTime()) {
    int headerH = display.height() * 16 / 100; // now 16% of display height

    uint16_t fg = GxEPD_WHITE;
    uint16_t bg = GxEPD_BLACK;

    // Dynamic content
    char timeStr[6]; // HH:MM
    snprintf(timeStr, sizeof(timeStr), "%02d:%02d", now.tm_hour, now.tm_min);

    char envStr[20]; // temperature + humidity
    snprintf(envStr, sizeof(envStr), "%.1f""C %.0f%%RH", temperature, humidity);

    String h2Str;
    String h3Str;
    if(selected == 0) { // header selected -> show alternate text
        h2Str = "PROVISIONING";
        h3Str = "OATH RFSH";
    } else { // normal display
        if(WiFi.status() == WL_CONNECTED) h2Str = WiFi.SSID();
        else h2Str = "Offline";
        char vbatStr[12];
        snprintf(vbatStr, sizeof(vbatStr), "VBAT: %.2fV", vbat);
        h3Str = String(vbatStr);
    }

    // Widths
    int charW = 6 * 2;  // textSize=2
    int h1W = 5 * charW + charW;       // HH:MM
    int h3W = h3Str.length() * charW + charW;
    int totalW = display.width();
    int h2W = totalW - h1W - h3W;

    display.setPartialWindow(0, 0, totalW, headerH);
    display.firstPage();
    do {
        // H1: time (top line)
        display.fillRect(0, 0, h1W, headerH / 2, GxEPD_WHITE);
        display.setTextColor(GxEPD_BLACK);
        display.setCursor(2, 2); // top of header
        display.setTextSize(2);
        display.print(timeStr);

        // H1 second line: temperature + humidity
        display.setCursor(2, headerH / 2 + 4);
        display.setTextSize(2);
        display.print(envStr);

        // H2: SSID / PROVISIONING
        bool invert_section = (highlight_section == 0 && invert); // only H2 is highlightable now
        display.fillRect(h1W, 0, h2W, headerH/2, invert_section ? bg : fg);
        display.setTextColor(invert_section ? fg : bg);
        display.setCursor(h1W + 2, 2);
        display.setTextSize(2);

        String h2Display = h2Str;
        int maxChars = h2W / charW;
        if(h2Display.length() > maxChars) h2Display = h2Display.substring(0, maxChars);
        display.print(h2Display);

        // H3: VBAT / OATH RFSH
        invert_section = (highlight_section == 1 && invert); // H3 highlightable
        display.fillRect(h1W + h2W, 0, h3W, headerH, invert_section ? bg : fg);
        display.setTextColor(invert_section ? fg : bg);
        display.setCursor(h1W + h2W + 2, 2);
        display.setTextSize(2);
        display.print(h3Str);

    } while(display.nextPage());
}
// Helper: format tm into a string
String formatDate(const tm &t) {
    // Example: "Monday, January 15 2026"
    char buf[32];
    strftime(buf, sizeof(buf), "%A, %B %d %Y", &t);
    return String(buf);
}
void drawBody(const Date &d, tm now = getTime()) {
    int headerH = display.height() * 16 / 100;
    int bodyH = display.height() - headerH;

    int leftW = display.width() * 10 / 100;
    int midW  = display.width() * 80 / 100;
    int rightW = display.width() - leftW - midW;

    display.setPartialWindow(0, headerH, display.width(), bodyH);
    display.firstPage();
    do {
        // Left section
        display.fillRect(0, headerH, leftW, bodyH, GxEPD_WHITE);
        display.setTextColor(GxEPD_BLACK);
        display.setCursor(5, headerH + bodyH / 2 - 4);
        display.setTextSize(2);
        display.print("<-");

        // Right section
        display.fillRect(leftW + midW, headerH, rightW, bodyH, GxEPD_WHITE);
        display.setTextColor(GxEPD_BLACK);
        display.setCursor(leftW + midW + 5, headerH + bodyH / 2 - 4);
        display.setTextSize(2);
        display.print("->");

        // Middle section
        display.fillRect(leftW, headerH, midW, bodyH, GxEPD_WHITE);
        display.setTextColor(GxEPD_BLACK);
        display.setCursor(leftW + 5, headerH);
        display.setTextSize(2);

        // Convert Date to tm
        tm nowTm = dateToTm(d);
        String dateStr = formatDate(nowTm);
        display.println(dateStr);

        if (!viewingEvents) {
            // --- FORECAST DISPLAY ---
            auto it = forecast_map.find(d);
            if (it != forecast_map.end()) {
                const Forecast &fc = it->second;

                display.print("Weather: ");
                switch(fc.weather_code_daily) {
                    case CLEAR_SKIES: display.println("Clear"); break;
                    case CLOUDY: display.println("Cloudy"); break;
                    case OVERCAST: display.println("Overcast"); break;
                    case FOGGY: display.println("Foggy"); break;
                    case DRIZZLE: display.println("Drizzle"); break;
                    case RAINY: display.println("Rain"); break;
                    case SNOWY: display.println("Snow"); break;
                    case STORMY: display.println("Storm"); break;
                    default: display.println("Unknown"); break;
                }
                display.printf("Min: %.1f C Max: %.1f C\n", fc.temperature_daily_min, fc.temperature_daily_max);

                // Hourly table as before (rows, two columns)
                display.println();
                display.setTextSize(1);
                tm currTime = now;
                bool isToday = (d.year == currTime.tm_year &&
                                d.month == currTime.tm_mon &&
                                d.day == currTime.tm_mday);
                int startHour = isToday ? currTime.tm_hour : 0;
                int rowHeight = 10;
                int leftColX = leftW + 5;
                int rightColX = leftW + midW / 2 + 5;
                auto starty = display.getCursorY();
                for (int h = startHour; h < 24; ++h) {
                    int colX = (h < 12) ? leftColX : rightColX;
                    int row = ((h) % 12);
                    int y = starty + row * rowHeight;

                    bool invert = isToday && h == currTime.tm_hour;
                    uint16_t fg = invert ? GxEPD_WHITE : GxEPD_BLACK;
                    uint16_t bg = invert ? GxEPD_BLACK : GxEPD_WHITE;

                    display.fillRect(colX, y, midW / 2 - 10, rowHeight, bg);
                    display.setTextColor(fg);
                    display.setCursor(colX, y);

                    char hourStr[15];
                    snprintf(hourStr, sizeof(hourStr), "%02d:00", h);
                    display.print(hourStr);
                    display.print(" | ");
                    display.printf("%.1f C | ", fc.temperature_hourly[h]);

                    switch(fc.weather_code_hourly[h]) {
                        case CLEAR_SKIES: display.println("Clear"); break;
                        case CLOUDY: display.println("Cloudy"); break;
                        case OVERCAST: display.println("Overcast"); break;
                        case FOGGY: display.println("Foggy"); break;
                        case DRIZZLE: display.println("Drizzle"); break;
                        case RAINY: display.println("Rain"); break;
                        case SNOWY: display.println("Snow"); break;
                        case STORMY: display.println("Storm"); break;
                        default: display.println("Unknown"); break;
                    }
                }
            }

            // --- EVENT COUNT DISPLAY ---
            auto range = event_map.equal_range(d);
            int eventCount = std::distance(range.first, range.second);
            if (eventCount > 0) {
                display.println();
                display.setTextSize(2);
                display.print(eventCount);
                display.println(" Events on this day. Press ENTER to browse.");
            }

        } else {  auto range = event_map.equal_range(d);
            int eventCount = std::distance(range.first, range.second);

            if (eventCount == 0) {
                display.println("No events to display.");
            } else {
                // Advance iterator to current eventIndex
                auto it = range.first;
                std::advance(it, eventIndex % eventCount);
                const Event &ev = it->second;

                display.setTextSize(2);

                // --- Extra blank line before summary ---
                display.println();

                // --- Center the text horizontally ---
                int bodyWidth = midW - 10; // margin
                int cursorX = leftW + 5;

                // Helper lambda to center text
                auto printCentered = [&](const String &s) {
                    int16_t x1, y1;
                    uint16_t w, h;
                    display.getTextBounds(s, 0, 0, &x1, &y1, &w, &h);
                    display.setCursor(cursorX + (bodyWidth - w)/2, display.getCursorY());
                    display.println(s);
                };

                // Summary
                printCentered("Summary:");
                printCentered(ev.summary);

                // Description
                printCentered("Description:");
                printCentered(ev.description);

                // Start / End times
                char buf[32];
                strftime(buf, sizeof(buf), "%d/%m/%Y %H:%M:%S", &ev.startTime);
                printCentered(String("Start: ") + buf);
                strftime(buf, sizeof(buf), "%d/%m/%Y %H:%M:%S", &ev.endTime);
                printCentered(String("End:   ") + buf);

                // Event counter [current/total] below
                display.println();
                display.setTextSize(2);
                printCentered("[" + String(eventIndex+1) + "/" + String(eventCount) + "]");

                // Exit label at the bottom
                display.println();
                printCentered("Press ENTER to exit");
            }

        }

    } while(display.nextPage());
}

// Full refresh
void fullRefresh(Date &d) {
    display.setFullWindow();
    display.firstPage();
    do {
        drawHeader(selected == 0, selected == 0 ? header_section : -1);
        drawBody(d);
    } while(display.nextPage());
    partial_count = 0;
}
// Helper: format tm into a string

int lastMinute = -1; // global/static, stores last displayed minute

void updateTimePartial() {
    tm now = getTime();
    if(now.tm_min != lastMinute) {
        lastMinute = now.tm_min;

        // Read temperature & humidity
        sensors_event_t humidityEvent, tempEvent;
        if (sht4.getEvent(&humidityEvent, &tempEvent)) {
            humidity = humidityEvent.relative_humidity;
            temperature = tempEvent.temperature;
        }

        // Prepare HH:MM string
        char timeStr[6];
        snprintf(timeStr, sizeof(timeStr), "%02d:%02d", now.tm_hour, now.tm_min);

        // Prepare temperature + humidity string
        char envStr[20];
        snprintf(envStr, sizeof(envStr), "%.1f""C %.0f%%RH", temperature, humidity);

        // Calculate H1 width (same as in drawHeader)
        int headerH = display.height() * 16 / 100; // updated header height
        int charW = 6 * 2; // textSize=2
        int h1W = 5 * charW + charW;

        // Partial update for H1 only
        display.setPartialWindow(0, 0, h1W, headerH);
        display.firstPage();
        do {
            display.fillRect(0, 0, h1W, headerH, GxEPD_WHITE);
            display.setTextColor(GxEPD_BLACK);

            // Top line: time
            display.setCursor(2, 2);
            display.setTextSize(2);
            display.print(timeStr);

            // Second line: temp + humidity
            display.setCursor(2, headerH / 2 + 4);
            display.setTextSize(2);
            display.print(envStr);

        } while(display.nextPage());
    }
}


void provisioning()
{
    Serial.println("Starting SoftAP WiFi provisioning (Arduino WiFiProv)");

    // Stop any previous session and disconnect WiFi
    WiFiProv.endProvision();
    if (WiFi.status() == WL_CONNECTED) {
        WiFi.disconnect(true, true);
    }

    // --- Display instructions on EPAPER ---
    display.fillScreen(GxEPD_WHITE);
    display.setTextColor(GxEPD_BLACK);
    display.setCursor(0, 20);
    display.setTextSize(2);
    display.println("WiFi Provisioning");
    display.println();
    display.println("1. Open provisioning app");
    display.println("2. Follow instructions to connect device");
    display.println("Press any button to cancel");
    display.display(true); // full refresh

    // BLE device name shown on phone
    const char *service_name = "CALENDAR";
    const char *pop = nullptr; // optional proof-of-possession

    // Start provisioning (SoftAP)
    WiFiProv.beginProvision(
            NETWORK_PROV_SCHEME_SOFTAP,
            NETWORK_PROV_SCHEME_HANDLER_NONE,
            NETWORK_PROV_SECURITY_0,
            pop,
            service_name,
            0, 0, true
    );

    Serial.println("Waiting for provisioning to complete...");

    // --- Wait for WiFi connection or cancellation ---
    bool canceled = false;
    while (WiFi.status() != WL_CONNECTED && !canceled) {
        delay(100);

        // Check buttons
        if (btn_pressed(BTN_UP) || btn_pressed(BTN_DOWN) ||
            btn_pressed(BTN_LEFT) || btn_pressed(BTN_RIGHT) || btn_pressed(BTN_ENTER)) {
            Serial.println("Provisioning canceled by user");
            canceled = true;
            break;
        }
    }

    // End provisioning session cleanly
    WiFiProv.endProvision();

    if (!canceled) {
        Serial.println("Provisioning complete");
    }

            String new_ssid = prefs.getString("sta_ssid", "");
            String new_pass = prefs.getString("sta_pass", "");

            prefs.end();
            prefs.begin("main", false);

            Serial.print("SSID: ");
            Serial.println(new_ssid);
            Serial.print("Password: ");
            Serial.println(new_pass);
            WiFiProv.endProvision();
            // Update UI
        }


void refresh() {
    Serial.println("Getting fresh token pair...");

    // Clear the display
    display.fillScreen(GxEPD_WHITE);

        display.setCursor(10, 20);
        display.setTextColor(GxEPD_BLACK);
        display.setTextSize(2);
        display.print("Listening for access code on serial...");
    display.display();

    // Regenerate token pair (user-implemented)
    regenTokenPair();

    // Trigger full refresh of UI

    Serial.println("Refresh complete");
}

void staticDraw(const Date &d, tm now) {
    // Set full window for e-paper
    selected = 1;
    viewingEvents=0;
    display.setFullWindow();
    display.firstPage();
    do {
        // Header: dynamic like normal
        drawHeader(selected == 0, selected == 0 ? header_section : -1,now);

        // Body: date-specific
        drawBody(d,now);



    } while(display.nextPage());
}
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
void loop(void *arg) {

    auto creator = static_cast<TaskHandle_t>(arg);
    xTaskNotifyGive(creator);
    vTaskDelete(nullptr);   // delete this task when done
}

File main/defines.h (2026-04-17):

//
// Created by jaygee on 08.02.26.
//
#pragma once
// Pins
#define CS_PIN    35
#define FRAM_CS   5
#define DC_PIN    17
#define RST_PIN   16
#define BUSY_PIN  4

#define BTN_LEFT     39
#define BTN_DOWN   36
#define BTN_UP   38
#define BTN_RIGHT  37
#define BTN_ENTER  6
#define INCLUDE_vTaskDelete 1

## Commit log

2026-01-31 Project created and pushed to github
    [app3M_fat9M_16MB.csv, app3M_fat9M_fact512k_16MB.csv, app3M_spiffs9M_fact512k_16MB.csv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]
2026-04-17 Date compare operator fixed
    [main.cpp]
2026-04-17 Added docs
    [SmartCalendar_Mateusz.Kowalec.brd, SmartCalendar_Mateusz.Kowalec.sch]
